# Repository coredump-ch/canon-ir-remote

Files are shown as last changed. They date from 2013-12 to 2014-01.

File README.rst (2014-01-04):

DIY Canon IR Remote
===================

Inspiration:

- http://www.thingiverse.com/thing:9914
- http://www.doc-diy.net/photo/eos_ir_remote/

Canon RC-1 IR remote control protocol:

- http://www.doc-diy.net/photo/rc-1_hacked/index.php

Blogpost about this project (German):
http://www.coredump.ch/2014/01/04/diy-canon-ir-fernausloser/

Code
----

The code is written in C for the Atmel ATtiny13a microcontroller, running at
9.6MHz without the ``CKDIV8`` fuse set.

To build the code::

    cd code
    make

The makefile is configured for the ATtiny13a. First set the fuses::

    make setfuses

To upload the hex file to the microcontroller::

    make upload

The code is based on the work of Luk from `doc-diy.net
<http://www.doc-diy.net>`__ (http://www.doc-diy.net/photo/eos_ir_remote/). My
changes are licensed under the MIT license.

3D Model
--------

In the file ``model/canon_ir_v2.scad`` you can find the OpenSCAD sourcecode for
my remote 3D model. After a conversion to the STL format it can be printed on a
regular 3D printer.

The model is based on the design by Ted Lin
(http://www.thingiverse.com/thing:9914). The modified version is licensed as CC
BY-SA.

Licenses
--------

- Sourcecode: MIT License
- Case: CC BY-SA 3.0

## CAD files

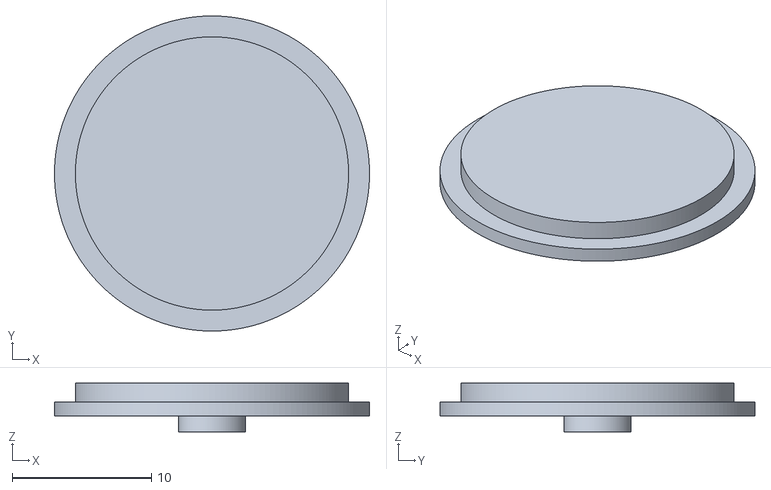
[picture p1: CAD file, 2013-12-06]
model/button.stl
22.6 x 22.6 x 3.50

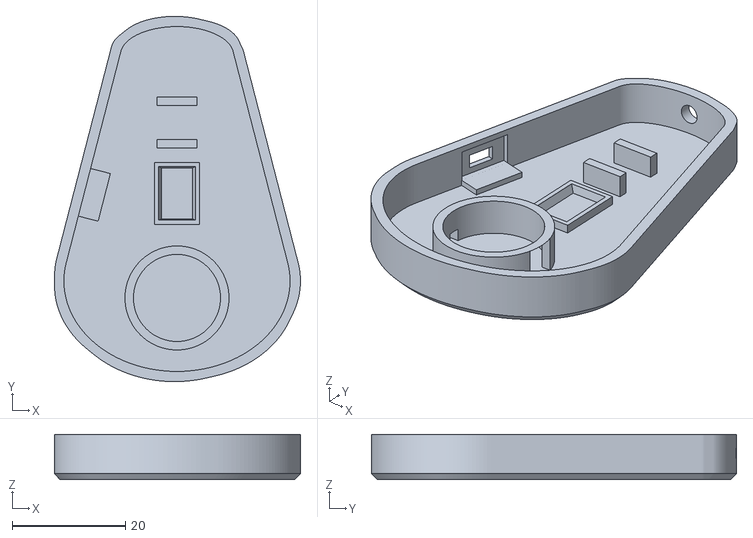
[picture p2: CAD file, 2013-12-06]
model/bottom.stl
43.5 x 64.6 x 8.05

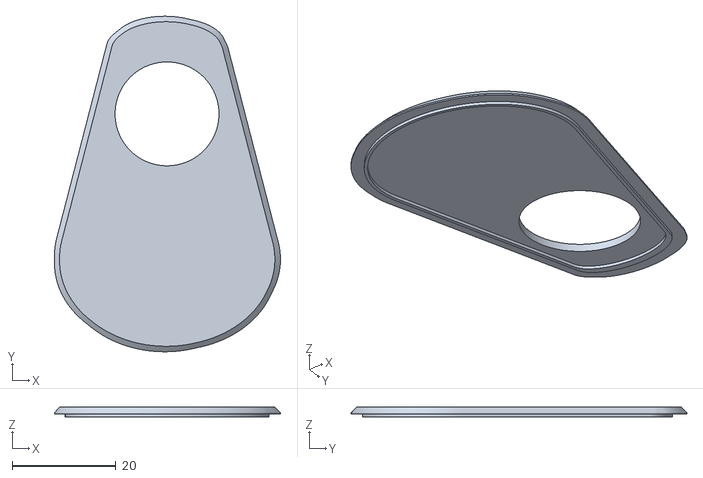
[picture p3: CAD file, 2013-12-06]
model/top.stl
43.5 x 64.6 x 1.90

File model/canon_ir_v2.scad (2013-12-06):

/**
 * Canon IR remote case v2.0.
 * Based on the design by Ted Lin (http://www.thingiverse.com/thing:9914).
 *
 * Author: Danilo Bargen (http://www.thingiverse.com/dbrgn)
 * License: CC BY-SA
 */


// VARIABLES

// Inner height of case (cutout).
CASE_H = 6.7;

// Height of ATtiny holder
ATT_H = 1.35;

// Height of button holder
BTN_H = 3.5;

// Increase this to get "rounder" curves.
// This will increase compilation time.
RES = 150;


// MAIN

// Comment the parts you want to hide.
part_top();
part_bottom();
part_button();


// PARTS

module part_top() {
	// Main parts
	difference() {
		casing();
		cutouts();
		halving(-1);
	}
	// Small inner ring
	translate([0,0,0.5]) intersection() {
		translate([0,20,2.8])
			cube([100,100,1], center=true);
		difference() {
			scale([0.98,0.98,1]) case_base(CASE_H - 1);
			scale([0.95,0.95,1]) case_base(CASE_H - 1);
		}
	}
}

module part_bottom() {
	difference() {
		casing();
		cutouts();
		halving(1);
	}
	battery_holder_cr1220([0,-3,0]);
	attiny([0,15.5,0]);
	button([0,28,0]);
	slider_support();
}

module part_button() {
	translate([0,28,2.35]) union() {
		cylinder(h=2.35, r=9.8, $fn=RES);
		cylinder(h=1, r=11.3, $fn=RES);
	}
	translate([0,28,1.2]) cylinder(h=2.7, r=2.4, $fn=RES);
}

// Plane to remove top/bottom half of the model
// Use a "side" value of -1 for the lower half,
// and 1 for the upper half.
module halving(side) {
	translate([0,0,side*10+(CASE_H/2)])
		cube([100,100,20], center=true);
}


// MODULES

// The basic shape of the remote.
module case_base(h)
{
	linear_extrude(height=h, center=true) hull()
	{
		translate([0,40]) scale([1,0.5]) circle(10, $fn=RES);
		scale([1,0.8]) circle(20, $fn=RES);
	}
}

// Add rounded edges to the case.
module casing() {
	minkowski() {
		case_base(CASE_H - 1);
		sphere(2);
	}
}

// Cutouts
module cutouts() {
	slider_rot = asin(10/40);
	slider_x = 16.74;
	slider_y = 40 - cos(slider_rot)*25;

	union() {
		// LED Hole
		translate([0,47.5,0]) rotate([90,0,0]) {
			cylinder(h=3, r=1.5, $fn=RES);
		}

		// Inside
		case_base(CASE_H);

		// Top button
		translate([0,28,2]) cylinder(h=3, r=10, $fn=RES);

		// Slider button
		translate([-slider_x,slider_y,0]) rotate([0,-90,-slider_rot])
		union() {
			cube([4.9,8.7,1], center=true);
			translate([-0.35,0,1]) cube([2.2,4.4,2], center=true);
		}
	}
}

// Battery holder for CR2032
module battery_holder_cr2032(transl) {
	height = 5;
	translate(transl)
	translate([0,0,-CASE_H/2+height/2])
	difference() {
		// Outer ring
		cylinder(h=height, r=12.05, center=true, $fn=RES);

		// Inner ring
		cylinder(h=height, r=11.05, center=true, $fn=RES);

		// Room for + connector
		translate([0,-3.85,-height/2]) cube([13.25,7.7,height]);

		// Room for - connector
		translate([-12.05,-1,-height/2]) cube([12.05,2,2]);
	}
}

// Battery holder for CR1220
module battery_holder_cr1220(transl) {
	height = 4.4+1.2;
	translate(transl)
	translate([0,0,-CASE_H/2+height/2])
	difference() {
		// Outer ring
		cylinder(h=height, r=9.2, center=true, $fn=RES);

		// Inner ring
		cylinder(h=height, r=7.7, center=true, $fn=RES);

		// Room for + connector
		translate([0,-2.5,-height/2]) cube([13.25,5,height]);

		// Room for - connector
		translate([-12.05,-1,-height/2]) cube([12.05,2,2]);
	}
}

// ATtiny13A
module attiny(transl) {
	translate(transl)
	translate([0,0,-CASE_H/2+ATT_H/2])
	difference() {
		cube([8,11,ATT_H], center=true);
		hull() {
			cube([5.5,9,ATT_H], center=true);
			translate([0,0,ATT_H/2]) {
				cube([6.5,9.5,0.1], center=true);
			}
		}
	}
}

// Button
module button(transl) {
	translate(transl)
	translate([0,0,-CASE_H/2+BTN_H/2])
	union() {
		// Main sides
		difference() {
			cube([7,9,BTN_H], center=true);
			cube([8,6,BTN_H], center=true);
		}
		// Top bars
		*translate([0,0,BTN_H/2+0.25]) difference() {
			cube([7,7,0.5], center=true);
			cube([7,5.5,0.5], center=true);
		}
	}
}

// Support platform for slider button
module slider_support() {
	slider_rot = asin(10/40);
	rotate([0,0,-slider_rot])
		translate([-18,11.1,-2.96])
			cube([3.7,8.7,1], center=true);
}

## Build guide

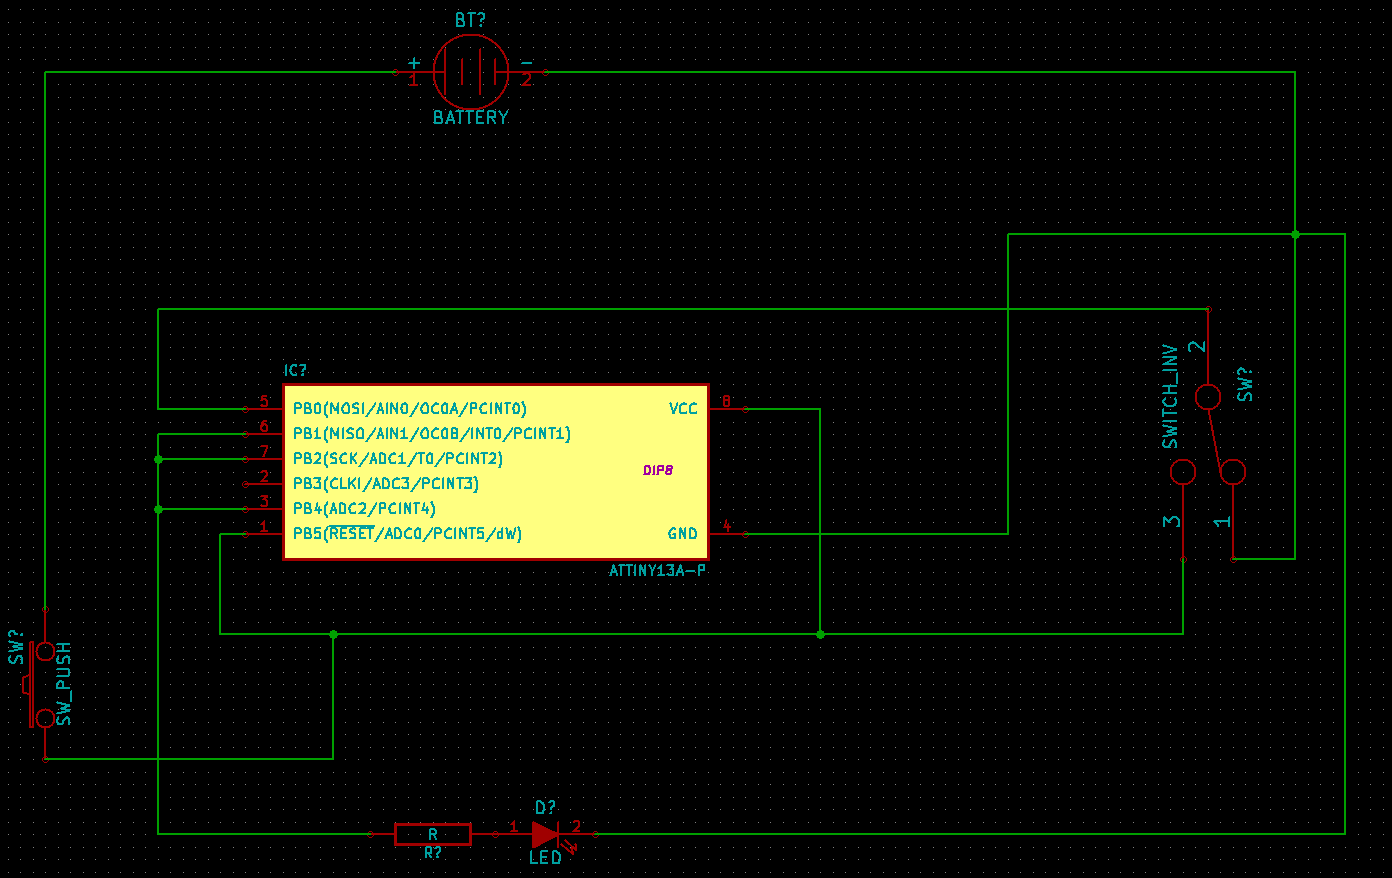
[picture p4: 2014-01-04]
wiring.png

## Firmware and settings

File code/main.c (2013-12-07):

#include <avr/io.h>
#include <avr/sleep.h>
#include <util/delay.h>

#define HPERIOD 0.01524
#define RATIO 0.4
#define NPULSES 16
#define INSTANT 7.33
#define DELAYED 5.36

#define LEDON  0b00010111
#define LEDOFF 0b00000001

void flash_led(void) {
    for(uint8_t i=0; i<NPULSES; i++) {
        PORTB = LEDON;
        _delay_ms(HPERIOD);
        PORTB = LEDOFF;
        _delay_ms(HPERIOD);
    }
}

int main(void) {
    // Set up I/O
    DDRB = _BV(PB1) | _BV(PB2) | _BV(PB4); // PB0 is input, PB1/2/4 are output
    PORTB = _BV(PB0); // Pull-up for input PB0

    // Reduce power consumption
    ADCSRA &= ~_BV(ADEN); // Disable ADC
    ACSR &= ~_BV(ACD); // Disable the analog comparator

    asm volatile ("nop");
    asm volatile ("nop");

    // Flash LED
    flash_led();
    if (PINB & _BV(PINB0)) {
        _delay_ms(INSTANT);
    } else {
        _delay_ms(DELAYED);
    }
    flash_led();

    // Power down
    set_sleep_mode(SLEEP_MODE_PWR_DOWN);
    sleep_mode();
}

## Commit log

2013-12-03 Added model
    [canon_ir_v2.scad]
2013-12-05 Further development of 3d model
    [canon_ir_v2.scad]
2013-12-06 First finished prototype of 3d model
    [bottom.stl, button.stl, canon_ir_v2.scad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]
2013-12-06 3d model: More spacing everyhwere
    [canon_ir_v2.scad]
2013-12-06 More model finetuning.
    - Decreased button pressing cylinder size
    - Made hole for slider button a little wider
    [bottom.stl, button.stl, canon_ir_v2.scad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]
2013-12-06 Finished 3d modelling
    [button.stl, canon_ir_v2.scad]
2014-01-04 Added wiring plan
